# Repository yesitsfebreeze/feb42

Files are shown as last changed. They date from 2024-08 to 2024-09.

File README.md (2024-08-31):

# Readme

This keyboard is a Hall-Effect replacement board for the idabao ID42.  
I made this because i use the ID42 as a daily driver and wanted to also use  
it for gaming.  
So natrually i wanted HE Switches :)  

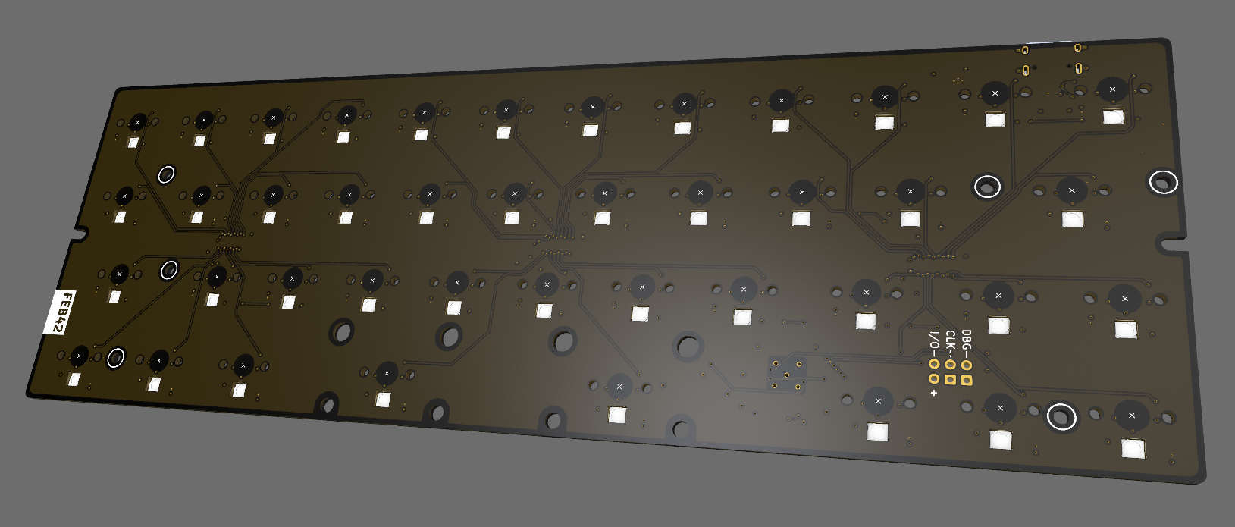
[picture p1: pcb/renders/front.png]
front

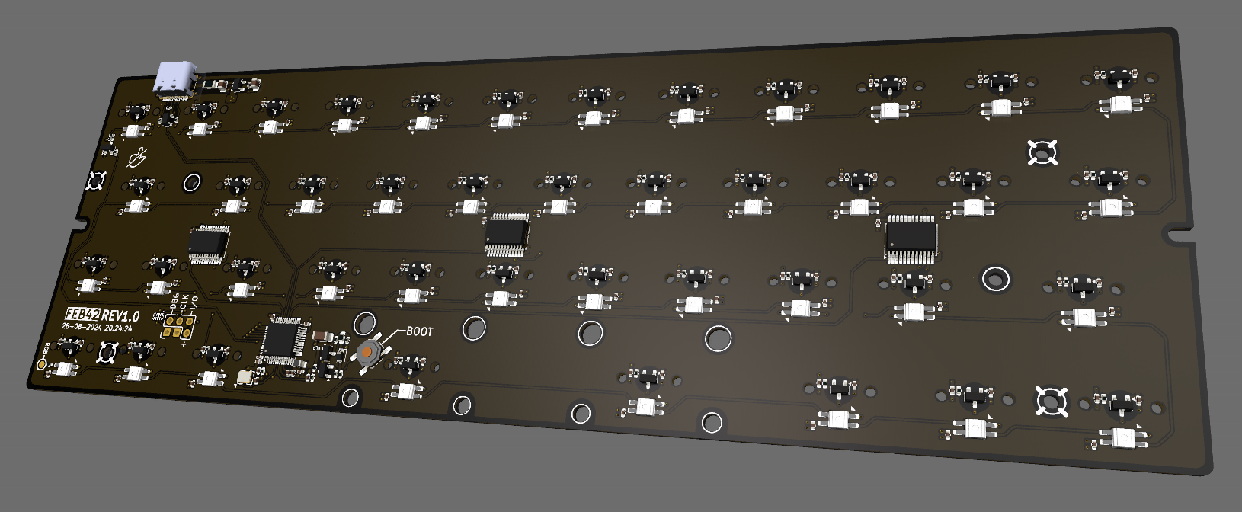
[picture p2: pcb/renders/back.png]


## Compiling

### Github actions
Just fork this repo, make ur changes and push them.  
The action will provide the built artifact.

### Locally
1. Download this repository
2. Install QMK for ur OS (`https://docs.qmk.fm/newbs_getting_started`)  
3. Open QMK MSYS
4. cd into the downloaded repository 
5. run `make compile` (optionally pass `km=my_custom_keymap` if you are not using the default one)

The Makefile will automatically link the keyboard into your qmk_firmware folder,  
no need to copy things over.

#### Troubleshooting
If qmk says there is no such function "compile", make sure ur system environment variable  
`QMK_HOME` is pointing to the cloned `qmk_firmware` folder.
Then restart QMK MSYS.

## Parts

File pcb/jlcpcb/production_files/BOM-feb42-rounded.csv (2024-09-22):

Comment | Designator | Footprint | LCSC
120R @ 100MHz | MFB2 | L_0805_2012Metric | C1015
1k | LMR2,R7 | R_0402_1005Metric | C11702
10u | BRC3 | C_1206_3216Metric | C13585
16MHz | CR2 | Crystal_SMD_3225-4Pin_3.2x2.5mm | C13738
10p | CR_C3,CR_C4,HEC1,HEC10,HEC11,HEC12,HEC13,HEC14,HEC15,HEC16,HEC17,HEC18,HEC19,HEC2,HEC20,HEC21,HEC22,HEC23,HEC24,HEC25,HEC26,HEC27,HEC28,HEC29,HEC3,HEC30,HEC31,HEC32,HEC33,HEC34,HEC35,HEC36,HEC37,HEC38,HEC39,HEC4,HEC40,HEC41,HEC42,HEC5,HEC6,HEC7,HEC8,HEC9,HECC1,HECC10,HECC11,HECC12,HECC13,HECC14,HECC15,HECC16,HECC17,HECC18,HECC19,HECC2,HECC20,HECC21,HECC22,HECC23,HECC24,HECC25,HECC26,HECC27,HECC28,HECC29,HECC3,HECC30,HECC31,HECC32,HECC33,HECC34,HECC35,HECC36,HECC37,HECC38,HECC39,HECC4,HECC40,HECC41,HECC42,HECC5,HECC6,HECC7,HECC8,HECC9,LEDC1,LEDC10,LEDC11,LEDC12,LEDC13,LEDC14,LEDC15,LEDC16,LEDC17,LEDC18,LEDC19,LEDC2,LEDC20,LEDC21,LEDC22,LEDC23,LEDC24,LEDC25,LEDC26,LEDC27,LEDC28,LEDC29,LEDC3,LEDC30,LEDC31,LEDC32,LEDC33,LEDC34,LEDC35,LEDC36,LEDC37,LEDC38,LEDC39,LEDC4,LEDC40,LEDC41,LEDC42,LEDC5,LEDC6,LEDC7,LEDC8,LEDC9,MC1,MC10,MC11,MC12,MC8,MC9,MPC1,MPC2,MPC3 | C_0402_1005Metric | C1525
USB-C 2.0 Receptacle | USB1 | USB_C | C165948
10u | PWRL1 | L_1210_3225Metric | C18184936
1N4148WS | BRD2 | D_SOD-323 | C2128
100 | R6 | R_0402_1005Metric | C25076
470 | LMR3,R3 | R_0402_1005Metric | C25117
100k | R9 | R_0402_1005Metric | C25741
10k | HER1,HER10,HER11,HER12,HER13,HER14,HER15,HER16,HER17,HER18,HER19,HER2,HER20,HER21,HER22,HER23,HER24,HER25,HER26,HER27,HER28,HER29,HER3,HER30,HER31,HER32,HER33,HER34,HER35,HER36,HER37,HER38,HER39,HER4,HER40,HER41,HER42,HER5,HER6,HER7,HER8,HER9,LMR1,R4,R5,R8 | R_0402_1005Metric | C25744
1.5k | R2 | R_0402_1005Metric | C25867
5.1k | USBR1,USBR2 | R_0402_1005Metric | C25905
1M | BRR9 | R_0402_1005Metric | C26083
1.1A | PWRF1 | Fuse_1206_3216Metric | C2760273
PRTR5V0U2X | USBD1 | SOT-143 | C2827688
1u | PWRC1,PWRC2 | C_0805_2012Metric | C28323
SLSS49E-3 | HE1,HE10,HE11,HE12,HE13,HE14,HE15,HE16,HE17,HE18,HE19,HE2,HE20,HE21,HE22,HE23,HE24,HE25,HE26,HE27,HE28,HE29,HE3,HE30,HE31,HE32,HE33,HE34,HE35,HE36,HE37,HE38,HE39,HE4,HE40,HE41,HE42,HE5,HE6,HE7,HE8,HE9 | SOT-23 | C2904393
10n | MC13,MC14,MC15 | C_0402_1005Metric | C307413
SW_Push | BS1 | SW_SPST_TL3342 | C318884
LM3670MF | SD1 | TSOT-23-5 | C477918
SK6812 | LED1,LED10,LED11,LED12,LED13,LED14,LED15,LED16,LED17,LED18,LED19,LED2,LED20,LED21,LED22,LED23,LED24,LED25,LED26,LED27,LED28,LED29,LED3,LED30,LED31,LED32,LED33,LED34,LED35,LED36,LED37,LED38,LED39,LED4,LED40,LED41,LED42,LED5,LED6,LED7,LED8,LED9 | SK6812-MINI-E | C5149201
STM32F411CEU6 | U1 | QFN-48-1EP_7x7mm_P0.5mm_EP5.6x5.6mm | C60420
PW_LED 0603 | D1 | LED_0603_1608Metric | C7371898
BSS138 | LM1 | SOT-23 | C82045
2N7002 | Q1,Q2 | SOT-23 | C8545
CD74HC4067SM | MP1,MP2,MP3 | SSOP-24_5.3x8.2mm_P0.65mm | C98457

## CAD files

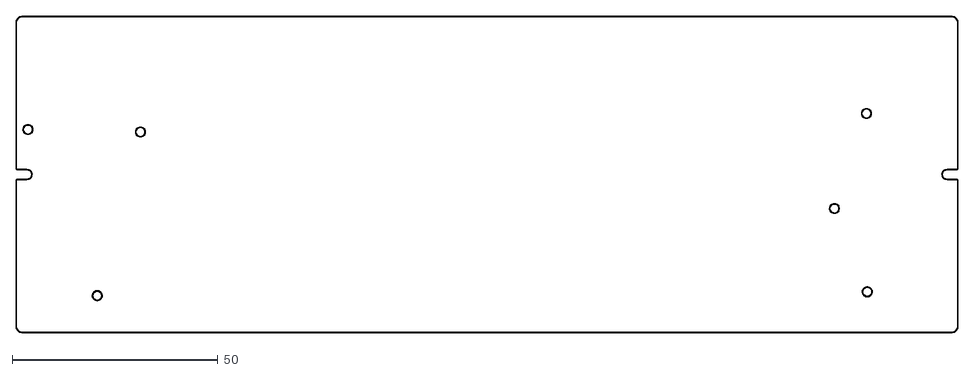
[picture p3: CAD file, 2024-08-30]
pcb/feb42-outline-Edge_Cuts.dxf
228.8 x 76.8
